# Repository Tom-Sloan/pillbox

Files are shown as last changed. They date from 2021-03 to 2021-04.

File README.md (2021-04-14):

# pillbox
*Folders*
<br />Desktop App               -> the code for the windows 10 app (on branch -> master)
<br />Phone App                 -> the code for the android phone app
<br />Pillbox Hardware          -> all files for the hardware (not incl. arduino code)
<br />Pillbox Software          -> pillbox arduino code

*Files*
<br />final_video               -> final demo video
<br />GuideToWritingReports     -> the doc given about how to write reports
<br />Reports and Presentation  -> everything written during the course

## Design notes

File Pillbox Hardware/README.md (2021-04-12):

# pillbox
*Folders*
bletest         -> code for desktop and phone app to test with
i2ctester       -> code found online that scans for connected i2c devices (https://playground.arduino.cc/Main/sourceblock_1/index.txt?action=sourceblock&num=1)
motor_ic_test   -> code used to test to see if the motor drivers
Pillbox         -> the code for the entire pillbox

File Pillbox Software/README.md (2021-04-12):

# pillbox
*Folders*
<br />bletest         -> code for desktop and phone app to test with
<br />i2ctester       -> code found online that scans for connected i2c devices (https://playground.arduino.cc/Main/sourceblock_1/index.txt?action=sourceblock&num=1)
<br />motor_ic_test   -> code used to test to see if the motor drivers
<br />Pillbox         -> the code for the entire pillbox

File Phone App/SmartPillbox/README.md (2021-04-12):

# SmartPillbox
4th year capstone project

Android studio application built to perform the following tasks:
  1. Allow a user to add a medication to their schedule.
  2. Show the user their medication schedule.
  3. Show a user their adherance to said schedule.
  4. Give notifications to the user when it is time to take a medication.
  5. Transfer medication schedule via Bluetooth to an Arduino-based smart pillbox.
  
Features:
  1. Google Sign-in.
  2. Firebase authentication.
  3. Notifications added to Google calendar.

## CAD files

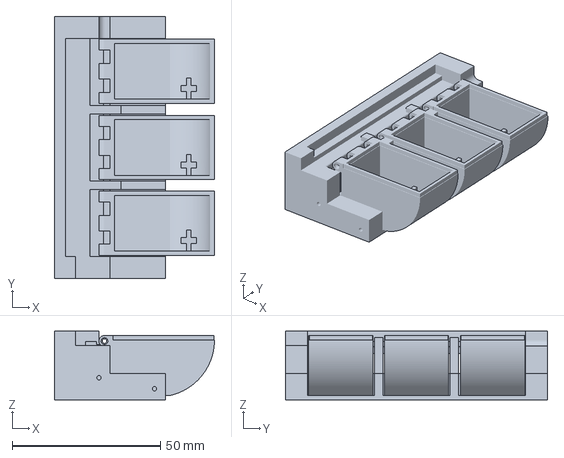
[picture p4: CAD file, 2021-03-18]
Pillbox Software/Pillbox/3d Prints/3MF/armstructureMini.3mf
54.0 x 88.5 x 23.2 mm

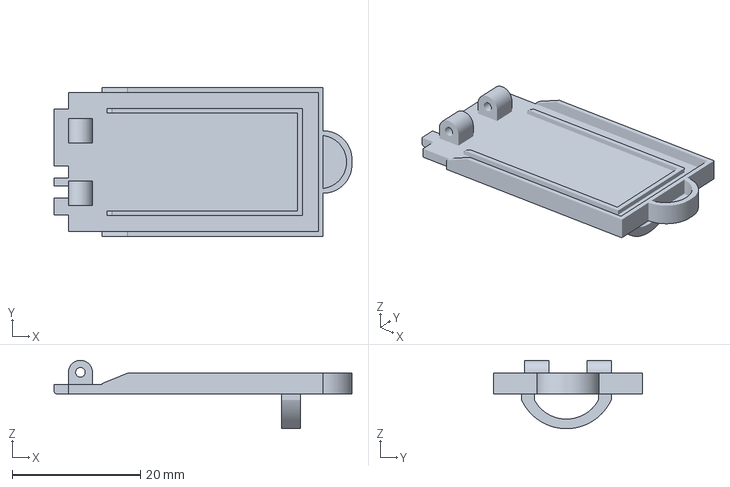
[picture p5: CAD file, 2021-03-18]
Pillbox Software/Pillbox/3d Prints/3MF/Lid 1/Lid1_v4.3mf
46.5 x 23.2 x 10.7 mm

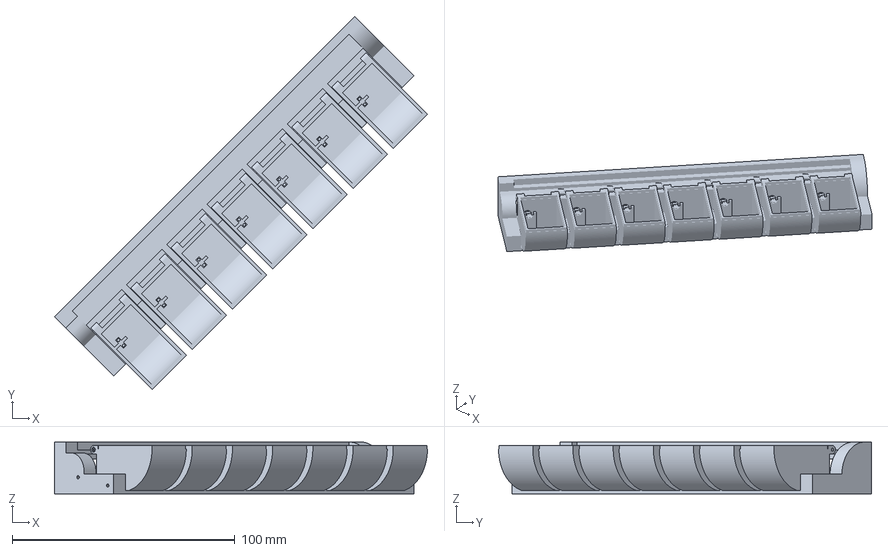
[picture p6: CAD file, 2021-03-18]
Pillbox Software/Pillbox/3d Prints/3MF/armstructureV2.3mf
167.3 x 167.3 x 23.2 mm

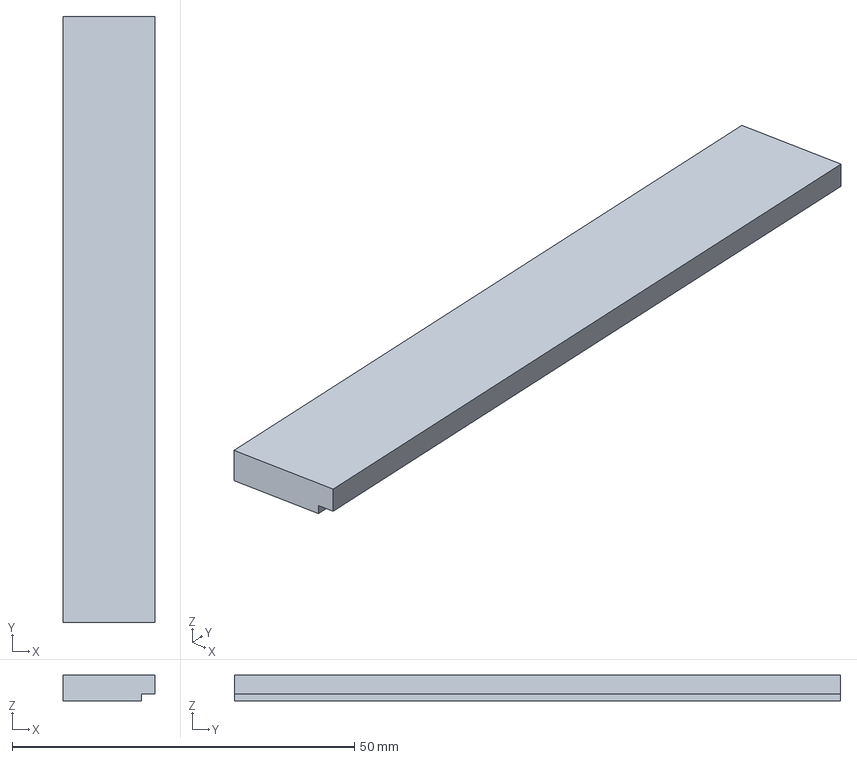
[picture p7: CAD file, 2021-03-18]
Pillbox Software/Pillbox/3d Prints/3MF/lidtopv2_mini.3mf
13.5 x 88.5 x 3.75 mm

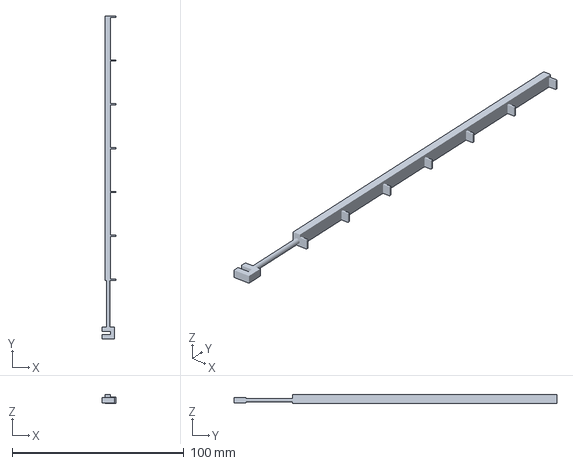
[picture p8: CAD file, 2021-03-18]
Pillbox Software/Pillbox/3d Prints/3MF/lockArm2.3mf
8.12 x 187.9 x 5.15 mm

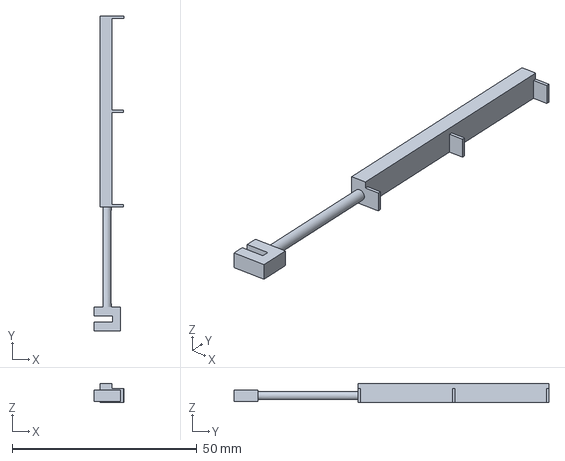
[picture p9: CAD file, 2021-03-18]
Pillbox Software/Pillbox/3d Prints/3MF/lockArm2_mini.3mf
8.02 x 85.3 x 5.15 mm

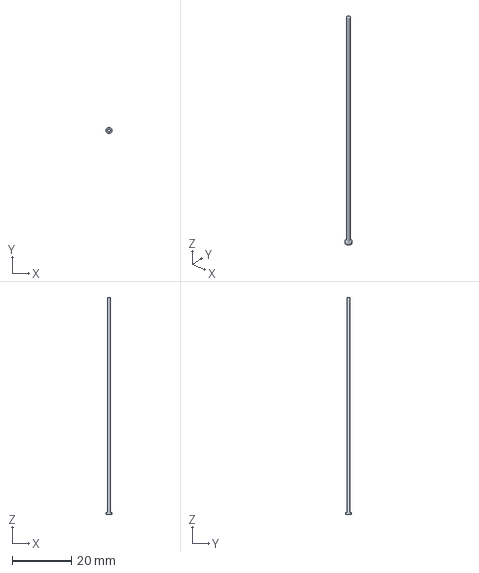
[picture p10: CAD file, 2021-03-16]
Pillbox Software/Pillbox/3d Prints/3MF/AxelLong.3mf
2.06 x 2.06 x 73.0 mm

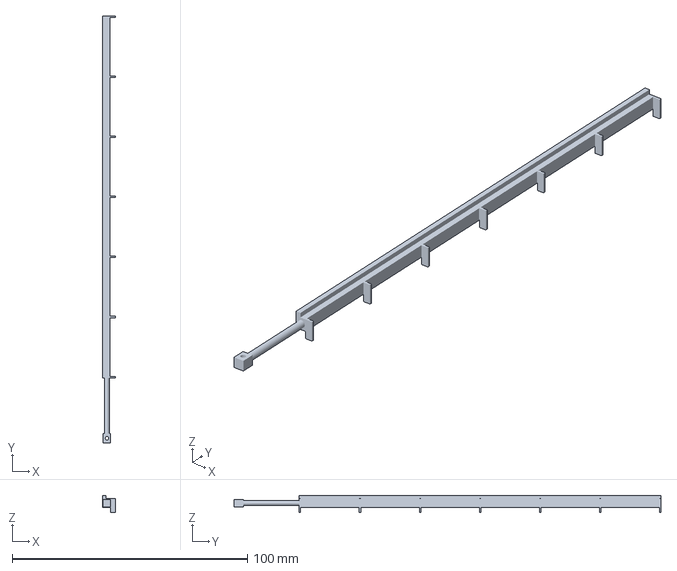
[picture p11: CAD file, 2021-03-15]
Pillbox Software/Pillbox/3d Prints/3MF/LockArm.3mf
5.50 x 181.3 x 7.40 mm

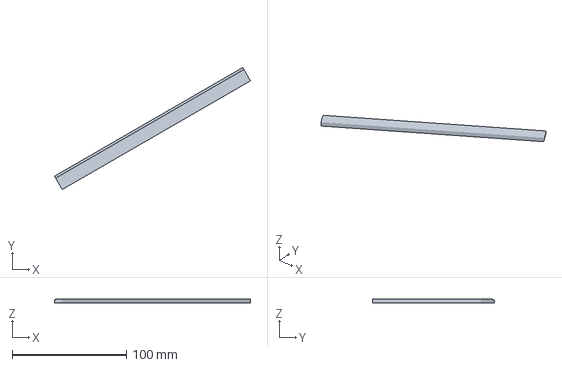
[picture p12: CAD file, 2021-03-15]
Pillbox Software/Pillbox/3d Prints/3MF/lidtopv2.3mf
171.7 x 106.9 x 3.75 mm

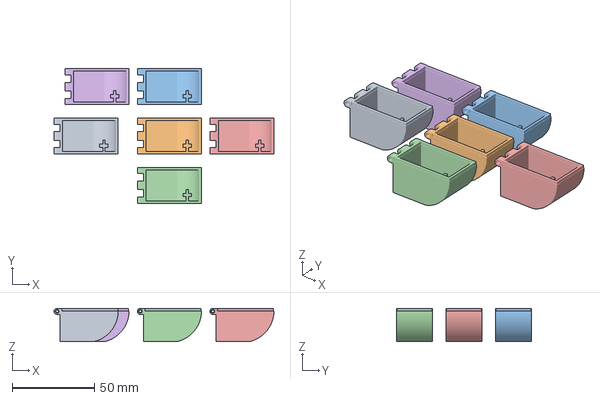
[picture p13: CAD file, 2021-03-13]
Pillbox Software/Pillbox/3d Prints/3MF/6 slots.3mf
133.6 x 81.8 x 20.2 mm

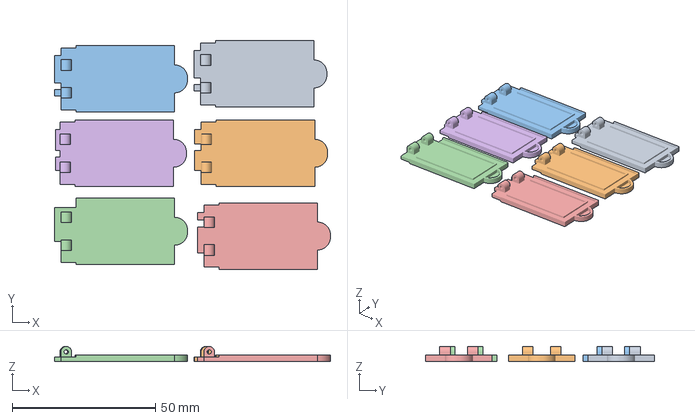
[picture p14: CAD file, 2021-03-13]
Pillbox Software/Pillbox/3d Prints/3MF/6 lids_1_2_7_4_5_6.3mf
96.5 x 79.9 x 5.25 mm

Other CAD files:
Pillbox Software/Pillbox/3d Prints/3MF/Lid2/Lid2_v4.3mf
Pillbox Software/Pillbox/3d Prints/3MF/Lid3/Lid3_v4.3mf
Pillbox Software/Pillbox/3d Prints/3MF/Lid4/Lid4_v4.3mf
Pillbox Software/Pillbox/3d Prints/3MF/Lid5/Lid5_v4.3mf
Pillbox Software/Pillbox/3d Prints/3MF/Lid6/Lid6_v4.3mf
Pillbox Software/Pillbox/3d Prints/3MF/Lid7/Lid7_v4.3mf
Pillbox Software/Pillbox/3d Prints/3MF/new lid.3mf
Pillbox Software/Pillbox/3d Prints/3MF/Axel.3mf
Pillbox Software/Pillbox/3d Prints/3MF/Lid 1/Lid1.3mf
Pillbox Software/Pillbox/3d Prints/3MF/Lid 1/Lid1_v2.3mf
Pillbox Software/Pillbox/3d Prints/3MF/Lid 1/Lid1_v3.3mf
Pillbox Software/Pillbox/3d Prints/3MF/Lid2/Lid2.3mf
Pillbox Software/Pillbox/3d Prints/3MF/Lid2/Lid2_v2.3mf
Pillbox Software/Pillbox/3d Prints/3MF/Lid2/Lid2_v3.3mf
Pillbox Software/Pillbox/3d Prints/3MF/Lid3/Lid3.3mf
Pillbox Software/Pillbox/3d Prints/3MF/Lid3/Lid3_v2.3mf
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

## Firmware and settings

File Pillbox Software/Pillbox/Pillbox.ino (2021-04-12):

//----------------------------------------TODO----------------------------------------
//1. turn special characters into array
//2. give serial more programming ability
//3. change to interupts on slot pin detection
//4. add support for multiple rows to have a slot unlocked at once (max theorically is 1 per row)
//5. change alarm to non-blocking
//6. move row detection to loop if to it always runs not only when there is a non special character in byte 5 (byte 6 in report)
//7. change event recording to include the interval and alarm if there was one (currently records as 00)
//8. make the use of the variable dataUsed more consistant
//9. I removed the calls to the restart function (default function 1) for debugging perposes

//----------------------------------------Notes----------------------------------------
//1. Servo mode is not modular
//2. There are a lot of serial.print calls. These are not required

/* References
 * https://www.ti.com/lit/ds/symlink/drv8834.pdf?ts=1618235438904
 * https://github.com/adafruit/Adafruit-MCP23017-Arduino-Library
 * https://learn.adafruit.com/bluefruit-nrf52-feather-learning-guide/bleuart
 * https://github.com/adafruit/Adafruit_VS1053_Library/blob/master/Adafruit_VS1053.h
 */

//----------------------------------------Libraries----------------------------------------
// For Bluetooth controls
#include <bluefruit.h>
#include <Adafruit_LittleFS.h>
#include <InternalFileSystem.h>

// For Music player include SPI, MP3 and SD libraries
#include <SPI.h>
#include <SD.h>
#include <Adafruit_VS1053.h>

// For sensors
#include "Adafruit_MCP23017.h"

//For Motors
#include <Servo.h>

//For time
#include "RTClib.h"
//----------------------------------------Variable Declaration----------------------------------------

// BLE Service
BLEDfu  bledfu;  // OTA DFU service
BLEDis  bledis;  // device information
BLEUart bleuart; // uart over ble
BLEBas  blebas;  // battery

// BLE Sim Variables
bool dataUsed = true;
String dataReceived = "";

// Player (noise and sd card)
#define VS1053_RESET   -1     // VS1053 reset pin (not used!)

#if defined(ARDUINO_NRF52832_FEATHER )
#define VS1053_CS       30     // VS1053 chip select pin (output)
#define VS1053_DCS      11     // VS1053 Data/command select pin (output)
#define CARDCS          27     // Card chip select pin
#define VS1053_DREQ     31     // VS1053 Data request, ideally an Interrupt pin

// Feather M4, M0, 328, nRF52840 or 32u4
#else
#define VS1053_CS       6     // VS1053 chip select pin (output)
#define VS1053_DCS     10     // VS1053 Data/command select pin (output)
#define CARDCS          5     // Card chip select pin
// DREQ should be an Int pin *if possible* (not possible on 32u4)
#define VS1053_DREQ     9     // VS1053 Data request, ideally an Interrupt pin
#endif

// SD card directory
String baseDir = "/";

// Music player object
Adafruit_VS1053_FilePlayer featherPlayer = Adafruit_VS1053_FilePlayer(VS1053_RESET, VS1053_CS, VS1053_DCS, VS1053_DREQ, CARDCS);


// Motor Variables (IC and Motor)
//This project was built to support a servo motor and a stepper, therefore use this var to toggle
bool isServo = false;

//Servo
float positions_servo[8] = {0, 25.7, 51.4, 77.1, 102.9, 128.6, 154.3, 180.0};
Servo myservo;
#define servoPin 15

//Stepper
int positions_stepper[4];

int finalPositions_long[8] = {0, 815, 1630, 2445, 3260, 4075, 4890, 5705}; //Position
int finalPositions_short[8] = {0, 228, 456, 684, 912, 1140, 1368, 1605}; //Position
int* finalPositions = finalPositions_short;

//Control variables for motor driver
#define stp 7 //on going high, motor moves 1 step
#define EN  8 //if off then the motor doesn't move
#define dirctn 9 //High goes 1 way, low another
#define slp 10 //if low the motor driver is off and uses much less power
#define MS1 11 //to control step size
#define MS2 12 // to control step size

//Alarm controling variables
int deltaTime = 1790; //Variable for control byte 1 (time to open in seconds)
int alarmTime = 0; // The time of the next alarm
String alarmData = ""; // Used to keep track of control bytes 0-5
bool moveOn = true; // Used to let the system know that the next alarm is known and to not look for another unless a message is recieved.
bool playedAlarm = true; // lets the system know if the slot has been unlocked

// Sensor variables
#define NUM_SENSORS 7 //bc i made a prototype with 3 sensors

//bc there is a max of 4 modules I hard coded this stuff, but if you make the arrays dynamic then the entire system will still work. I did set a hard coded limit on number of rows somewhere too (just search for a 4)
Adafruit_MCP23017 ioex[4]; //array that contains multiplexer objects
const int IOEX_ADDR[4] = {0x27, 0x26, 0x25, 0x24};  // possible addresses for the mux that this system supports
int numRows = 1; // current number of rows, used to see if there had been a change.

//contains the last btn states for the slots. See the btn debouncing arduino example for how it works.
bool lastBtnStates[4][7] = {
  {false, false, false, false},
  {false, false, false, false},
  {false, false, false, false},
  {false, false, false, false}
};
bool currentBtnStates[4][7] = {
  {false, false, false, false},
  {false, false, false, false},
  {false, false, false, false},
  {false, false, false, false}
};
long lastDebounceTime = 0; // the last time the output pin was toggled
long debounceDelay = 50; // the debounce time; increase if the output flickers

//Time object for RTC
RTC_DS3231 rtc;

//----------------------------------------END Variable Declaration----------------------------------------



//----------------------------------------Default Functions----------------------------------------
//Reset function. Call it with 'resetFunc();' and the device restarts.
void(* resetFunc) (void) = 0;

void setup() {
  //Comments used to make debugging easier. You can remove to make interaction with desktop easier
  Serial.begin(115200);
  Serial.println("\t Pillbox Serial");
  Serial.println("------------------------------\n");
  Serial.println("-----Starting Player------");
  playerInit(); //Sets up music and sd card
  Serial.println("-----SD and Volume Check------");
  startAlarm(3); //test beep to show that its working. Can remove

  Serial.println("-----Starting RTC------");
  RTCInit(); //Sets up the rtc

  Serial.println("-----Starting BT------");
  initBLE(); //Sets up ble

  Serial.println("-----Initializing Device------");
  set_base_setup(); //Sets up the required defaults (like next alarm, number of modules etc)
  Serial.println("-----Setup DONE------");
}

void loop() {
  Serial.print("Time");
  Serial.println(rtc.now().unixtime());

  //For ble communication. The arduino checks to see if there is a message
  if (bleuart.available()) {

    //adjust Time
    if (bleuart.peek() == 'A') {
      Serial.println("A Section");
      bleuart.read(); // peek() doesn't remove the letter from the buffer so we remove it here
      uint32_t unixTime = 0;
      int value = 0;
      //gets the values from bytes 7-15 into the unix time stamp interger format. this doesn't use dataREcieved bc I wrote it first
      while (bleuart.available()) {
        value = bleuart.read() - 48;
        unixTime = unixTime * 10 + value;
      }
      unixTime = (unixTime - value) / 10;
      rtc.adjust(DateTime(unixTime));

      // Recieving an alarm time
    } else if (bleuart.peek() == 'T') {
      if (!dataUsed) {
        char a = bleuart.read();
        Serial.println("T Section");
        uint32_t unixTime = 0;
        int value = 0;
        while (bleuart.available()) {
          int val = bleuart.read() - 48;
          if (val >= 0 && val <= 9) {
            value = val;
            unixTime = unixTime * 10 + value;
          }
        }

        String action =  "";
        action += dataReceived;
        action += "T";
        action += unixTime;
        Serial.println(action);
        addToActions(action);
      }
      // Request data
    } else if (bleuart.peek() == 'R') {
      if (!dataUsed) {
        Serial.println("R Section");
        while (bleuart.available()) {
          bleuart.read();
        }
        sendEvents("BLE");
      }

      //Unlock a row
    } else if (bleuart.peek() == 'U') {
      if (!dataUsed) {
        while (bleuart.available())
          bleuart.read();
        byte row = dataReceived.charAt(3) - '0';
        if (row < numRows) {
          openAllRow(row);
        }
        Serial.print("U Section => Unlocked row: ");
        Serial.println(row);
      }

      //Unlock a slot
    } else if (bleuart.peek() == 'M') { // Recieving an alarm time
      if (!dataUsed) {
        while (bleuart.available())
          bleuart.read();
        byte row = dataReceived.charAt(3) - '0';
        byte coln = dataReceived.charAt(4) - '0';
        if (row < numRows) {
          spotToOpen(row, coln);
        }
        Serial.print("M Section => Unlocked row: ");
        Serial.print(row);
        Serial.print("\t Coln: ");
        Serial.println(coln);
      }

      //Lock a row
    } else if (bleuart.peek() == 'L') { // Recieving an alarm time
      if (!dataUsed) {
        while (bleuart.available())
          bleuart.read();
        byte row = dataReceived.charAt(3) - '0';
        if (row < numRows) {
          lockedPosition(row);
        }
        Serial.print("L Section => locked row: ");
        Serial.println(row);
      }

      //Play an alarm
    }  else if (bleuart.peek() == 'P') {
      if (!dataUsed) {
        while (bleuart.available())
          bleuart.read();
        byte alarm = dataReceived.charAt(1) - '0';
        startAlarm(alarm);
        Serial.print("P Section => Played alarm: ");
        Serial.println(alarm);
      }
    }
    //
    else { // Recieving an instruction
      dataReceived = "";
      Serial.println("Recieved Message");
      while ( bleuart.available()  && bleuart.peek() != 'T' && bleuart.peek() != 'A' && bleuart.peek() != 'R' && bleuart.peek() != 'U' && bleuart.peek() != 'M' && bleuart.peek() != 'L' && bleuart.peek() != 'P') {

        uint8_t ch;
        ch = (uint8_t) bleuart.read();
        if (ch > 11) {
          dataUsed = false;
          dataReceived += ch  - 48;
        }
      }

      if (!dataUsed) {
        Serial.println("Processing message");

        // DO EVENT
        if (bleuart.peek() != 'T' && bleuart.peek() != 'A' && bleuart.peek() != 'R' && bleuart.peek() != 'U' && bleuart.peek() != 'M' && bleuart.peek() != 'L' && bleuart.peek() != 'P')
          processMessage(dataReceived);
      }
    }
  }

  //For serial communication. The arduino checks to see if there is a message
  if (Serial.available())
  {
    delay(2);
    if (Serial.peek() - '0'  >= 1 && Serial.peek() - '0' <= NUM_SENSORS) {
      char user_input;
      user_input = Serial.read();
      Serial.print("User Input: ");
      Serial.println(user_input - '0');
      Serial.println("GOING UP");
      spotToOpen(1, user_input - '0');

    } else if (Serial.peek() == 'B') {
      Serial.println("Setting Long");
      finalPositions = finalPositions_long;
      for (int i = 0; i < sizeof(finalPositions); i++) {
        Serial.println(finalPositions[i]);
      }

    } else if (Serial.peek() == 'S') {
      Serial.println("Setting Short");
      finalPositions = finalPositions_short;
      for (int i = 0; i < sizeof(finalPositions); i++) {
        Serial.println(finalPositions[i]);
      }
    } else if (Serial.find('R')) {
      sendEvents("SERIAL");

    }
    while (Serial.available()) {
      Serial.read();
    }
  }

  //Checks to see if the a slot has been opened
  checkSensors();

  //Checks to see which/if slot should be unlocked
  if (rtc.now().unixtime() - deltaTime <= alarmTime && alarmTime <= rtc.now().unixtime() + deltaTime ) { //1790
    if (!moveOn) {
      byte row = alarmData.charAt(3) - '0';
      byte coln = alarmData.charAt(4) - '0';

      Serial.print("Opening for alarm at: ");
      Serial.print(row);
      Serial.print("\t");
      Serial.println(coln);

      spotToOpen(row, coln);
      moveOn = true;
      playedAlarm = false;
    }
    //play alarm
    if (!playedAlarm && (rtc.now().unixtime() - 10 <= alarmTime && alarmTime <= rtc.now().unixtime() + 10)) {
      byte alarmNoise = alarmData.charAt(1) - '0';
      startAlarm(alarmNoise);
      playedAlarm = true;
    }

  } else {
    //used to make the system only look for an alarm if the next one is not known
    if (moveOn) {
      //used so if there is no alarm in actions.txt it doesn't go through this check needlessly
      if (alarmData != "") {
        Serial.println("Starting Alarm Set");
        byte row = alarmData.charAt(3) - '0';
        Serial.println("Got row");
        lockedPosition(row); //Locking previous row
        Serial.println("setLocked Pos");
        getNextAlarm();
        Serial.println("got next alarm");
        Serial.println(alarmData);
        moveOn = false;

      }
    }
  }
}

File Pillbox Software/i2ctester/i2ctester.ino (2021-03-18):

 // --------------------------------------
// i2c_scanner
//
// Version 1
//    This program (or code that looks like it)
//    can be found in many places.
//    For example on the Arduino.cc forum.
//    The original author is not know.
// Version 2, Juni 2012, Using Arduino 1.0.1
//     Adapted to be as simple as possible by Arduino.cc user Krodal
// Version 3, Feb 26  2013
//    V3 by louarnold
// Version 4, March 3, 2013, Using Arduino 1.0.3
//    by Arduino.cc user Krodal.
//    Changes by louarnold removed.
//    Scanning addresses changed from 0...127 to 1...119,
//    according to the i2c scanner by Nick Gammon
//    https://www.gammon.com.au/forum/?id=10896
// Version 5, March 28, 2013
//    As version 4, but address scans now to 127.
//    A sensor seems to use address 120.
// Version 6, November 27, 2015.
//    Added waiting for the Leonardo serial communication.
// 
//
// This sketch tests the standard 7-bit addresses
// Devices with higher bit address might not be seen properly.
//

#include <Wire.h>
#include "Adafruit_MCP23017.h"
const int IOEX_ADDR[4] = {0x27, 0x20, 0x25, 0x24}; //0x30; // A0 = A1 = A2 = 0
Adafruit_MCP23017 mcp;
Adafruit_MCP23017 mcp_2;
void setup()
{
  Wire.begin();

  Serial.begin(9600);
  while (!Serial);             // Leonardo: wait for serial monitor
  Serial.println("\nI2C Scanner");

  mcp.begin(IOEX_ADDR[0]);   
  for(int i = 0; i < 8; i++){
    mcp.pinMode(i, INPUT);
    mcp.pullUp(i, HIGH);  // turn on a 100K pullup internally
  }
  mcp_2.begin();   
  for(int i = 0; i < 8; i++){
    mcp_2.pinMode(i, INPUT);
    mcp_2.pullUp(i, HIGH);  // turn on a 100K pullup internally
  }
}


void loop()
{
  byte error, address;
  int nDevices;

  Serial.println("Scanning...");

  nDevices = 0;
  for(address = 1; address < 127; address++ ) 
  {
    // The i2c_scanner uses the return value of
    // the Write.endTransmisstion to see if
    // a device did acknowledge to the address.
    Wire.beginTransmission(address);
    error = Wire.endTransmission();

    if (error == 0)
    {
      Serial.print("I2C device found at address 0x");
      if (address<16) 
        Serial.print("0");
      Serial.print(address,HEX);
      Serial.println("  !");

      nDevices++;
    }
    else if (error==4) 
    {
      Serial.print("Unknown error at address 0x");
      if (address<16) 
        Serial.print("0");
      Serial.println(address,HEX);
    }    
  }
  if (nDevices == 0)
    Serial.println("No I2C devices found\n");
  else
    Serial.println("done\n");

   

  for(int i = 0; i < 8; i++){
    int stat = mcp.digitalRead(i);
    Serial.print("Location: ");
    Serial.print(i);
    Serial.print("\t");
    Serial.println(stat);
  }
  for(int i = 0; i < 8; i++){
    int stat = mcp_2.digitalRead(i);
    Serial.print("Location: ");
    Serial.print(i);
    Serial.print("\t");
    Serial.println(stat);
  }
  delay(1000);           // wait 5 seconds for next scan
}

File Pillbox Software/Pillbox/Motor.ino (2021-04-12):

//opens a specified slot
void spotToOpen(byte row, byte coln){
  if (isServo){
    myservo.write(positions_servo[coln]);  
  }else{
    int current_post = positions_stepper[row];
    int destination = finalPositions[coln];

    if (current_post > destination){
      runStepper(row, current_post - destination, false);
    }else{
      runStepper(row, destination - current_post, true);
    }
  }
}

//locks a row
void lockedPosition(byte row){
  Serial.println("Setting Locked row");
  
  if (isServo){
    myservo.write((positions_servo[1]+positions_servo[2])/2);   
  }else{
    int current_post = positions_stepper[row];
    Serial.println(current_post);
    int destination = (finalPositions[1] + finalPositions[2])/2;
    Serial.println(destination);
    if (current_post > destination){
      runStepper(row, current_post - destination, false);
    }else{
      runStepper(row, destination - current_post, true);
    }
  }
}

//open all slots in a row
//this is also the reset function called to set the initial motor position
void openAllRow(byte row){
  if (isServo){
    myservo.write(positions_servo[NUM_SENSORS]);   
  }else{
    runStepper(row, finalPositions[NUM_SENSORS] + 100, true);
    positions_stepper[row] = finalPositions[NUM_SENSORS];
    Serial.println(row);
    Serial.print("Setting stepper to");
    Serial.println(finalPositions[NUM_SENSORS]);
  }
}

//moves the arm of a row to a desired position 
void runStepper(byte row, int numSteps, bool forward){
   if (forward){
    ioex[row].digitalWrite(dirctn, LOW); 
    positions_stepper[row] += numSteps;
   }else{
    ioex[row].digitalWrite(dirctn, HIGH); 
    positions_stepper[row] -= numSteps;
   }
   ioex[row].digitalWrite(slp, HIGH);
   ioex[row].digitalWrite(EN, LOW);
   for (int x = 0; x < numSteps; x++) //Loop the stepping enough times for motion to be visible
    {
      digitalWrite(stp, HIGH); 
      delay(1);
      digitalWrite(stp, LOW); 
      delay(1);
    }
    ioex[row].digitalWrite(EN, HIGH);
    ioex[row].digitalWrite(slp, LOW);
    if (positions_stepper[row] < finalPositions[0]){
      positions_stepper[row]=finalPositions[0];
    }else if (positions_stepper[row] > finalPositions[NUM_SENSORS]){
      positions_stepper[row]=finalPositions[NUM_SENSORS];
    }
}

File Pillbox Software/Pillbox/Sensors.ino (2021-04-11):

//Sets up the sensors and the motor driver/servo
void initSensorIC(int location)
{
  
  Adafruit_MCP23017 mcp;

  // the breakout boards bought on amazon have a bug, remove this if not using them. 
  // or maybe its the adafruit library. Anyways this lets you use multiple modules
  if(location  != 1){
    mcp.begin(IOEX_ADDR[location]);      
  }else{
    mcp.begin();  
  }

  // sets up the pullups so i2c works, you can probably remove this if 
  for(int i = 0; i < NUM_SENSORS; i++){
    mcp.pinMode(i, INPUT);
    mcp.pullUp(i, HIGH);  // turn on a 100K pullup internally
  }
  
  //motor driver 
  if(!isServo){

    pinMode(stp, OUTPUT);
    
    mcp.pinMode(MS1, OUTPUT);
    mcp.pinMode(MS2, OUTPUT);
    mcp.pinMode(EN, OUTPUT);
    mcp.pinMode(slp, OUTPUT);
    mcp.pinMode(dirctn, OUTPUT);
    
    digitalWrite(stp, LOW);
    
    mcp.digitalWrite(dirctn, LOW);
    mcp.digitalWrite(MS1, LOW);
    mcp.digitalWrite(MS2, LOW);
    mcp.digitalWrite(EN, HIGH);
    mcp.digitalWrite(slp, LOW);

  //Servo 
  }else{
    myservo.attach(servoPin); 
  }

  //Adding sensors
  for(int i = 0; i < NUM_SENSORS; i++){
    lastBtnStates[location][i] = mcp.digitalRead(i);
    currentBtnStates[location][i] = mcp.digitalRead(i);
  }
  
  ioex[location] = mcp;
  Serial.println("Done add");
}

// for when the number of module changes
// calls to to initlize the new sensors and motor driver and sets the row to unlock 
void rowChange(int oldRowNum){

  if (oldRowNum<numRows){
    
    // add 
    Serial.println("Pre add");
    for (int i = 0; i<numRows-oldRowNum;i++){
      Serial.println("adding");
      String tmp = "index: ";
      tmp += i;
      tmp += "\t numRows: ";
      tmp += numRows;
      tmp += "\t oldrows: ";
      tmp += oldRowNum;
      Serial.println(tmp);
      if (oldRowNum+i < 4){
        initSensorIC(oldRowNum+i);
        Serial.println("Here");
        openAllRow(oldRowNum+i);
      }
    }
  }
}

// Checks the sensors for a slot unlocking event, debouncing method
void checkSensors()
{
  bool changedState = false;
  for(int row = 0; row<numRows; row++){
    for(int i = 0; i < NUM_SENSORS; i++){

      int stat = ioex[row].digitalRead(i);
      Serial.print("Location: ");
      Serial.print(row);
      Serial.print("\t");
      Serial.print(i);
      Serial.print("\t");
      Serial.println(stat);
      if (lastBtnStates[row][i] != stat){
        lastDebounceTime = millis();
      }
      lastBtnStates[row][i] = stat;
      
      if ((millis() - lastDebounceTime) < debounceDelay) {
        return;
      }

      if(currentBtnStates[row][i] != stat){
        currentBtnStates[row][i] = stat;
        if (!stat){
          Serial.print("Location: ");
          Serial.print(row);
          Serial.print("\t");
          Serial.print(i);
          Serial.print("\t");
          Serial.println(stat);
          addToEvents(row, i);
        }
      }
    }
  }
}

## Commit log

2021-02-05 adding current code
2021-03-03 large update. Working sensors, almost working motors. no alarms
2021-03-09 Adding 3d model w/gcode, small coding changes
    [AllLid.3mf, AllLid_but_4_6slot.3mf, Axel.3mf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]
2021-03-13 Big test push
    [6 lids_1_2_7_4_5_6.3mf, 6 slots.3mf, AllLid.3mf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]
2021-03-15 motor locations fixes and alarm file adds
    [Lid1_v4.3mf, LockArm.3mf, armstructureV2.3mf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]
2021-03-16 Cleaned some stuff up and fixed music player isssues
    [Feather_Player.ino]
2021-03-16 Added test code for phone and desktop uart communication
2021-03-16 Added btn debouncing, tested the system.
    [AxelLong.3mf, armstructureMini.3mf, new lid.3mf]
2021-03-17 fixed a bug in bletest
    [armstructureV2.3mf]
2021-03-18 many small changes
    [Lid1_v4.3mf, Lid2_v4.3mf, Lid3_v4.3mf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]
2021-04-14 Added 3D CAD Model Files
